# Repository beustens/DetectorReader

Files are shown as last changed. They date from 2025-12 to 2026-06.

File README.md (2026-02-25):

# Detector Reader
Short range, low cost UHF RFID reader based on RF detector

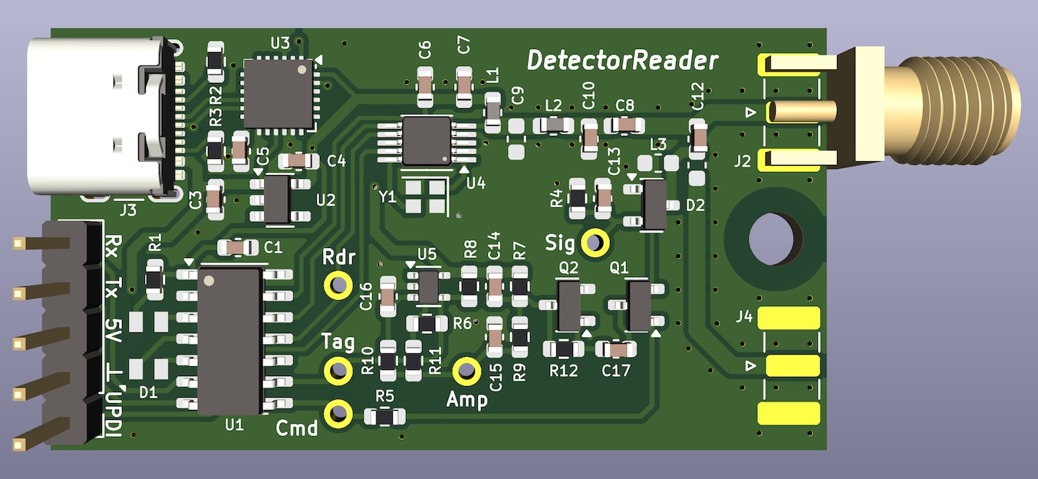
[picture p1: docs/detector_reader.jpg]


## Features
- 0.5m...2m read range depending on antenna and tag (8dBi patch antenna recommended)
- Monostatic or bistatic configuration
- ~15$ of production cost
- Compact size of 46x25mm
- Powersupply via 3...5V or USB
- EPCs are reported via UART or USB (serial) interface (115200 baud)

## Flashing
The firmware is written in AVR-C for the ATtiny814 using the platformIO IDE (extension for Visual STudio Code).

To transfer the firmware to the microcontroller, install [pymcuprog](https://pypi.org/project/pymcuprog/) and build yourself a UPDI programmer from a simple USB-UART converter and a 1kOhm resistor by connecting the resistor between Rx und Tx and connecting Rx to UPDI (Reset pin):
```
                        Vcc                     Vcc
                        +-+                     +-+
                         |                       |
 +---------------------+ |                       | +--------------------+
 | Serial port         +-+                       +-+  AVR device        |
 |                     |     +----------+          |                    |
 |                  TX +-----+   1k     +-----+    |                    |
 |                     |     +----------+     |    |                    |
 |                     |                      |    |                    |
 |                  RX +----------------------+----+ UPDI               |
 |                     |                           |                    |
 |                     +--+                     +--+                    |
 +---------------------+  |                     |  +--------------------+
                         +-+                   +-+
                         GND                   GND
```

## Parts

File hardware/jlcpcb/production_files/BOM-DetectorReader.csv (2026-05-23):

Comment | Designator | Footprint | LCSC | Quantity
MAX41460 | U4 | VSSOP-10_3x3mm_P0.5mm |  | 1
2.7p | C10 | C_0603_1608Metric |  | 1
2.7p | C12 | C_0603_1608Metric |  | 1
BC847C,215 | Q2 | SOT-23 |  | 1
CY7C65211-24LTXI | U3 | QFN-24-1EP_4x4mm_P0.5mm_EP2.6x2.6mm |  | 1
10u | C4 | C_0603_1608Metric |  | 1
IN-P32TATRGB | D1 | LED_SMD_IN-P32TATRGB |  | 1
Combo_Conn | J1 | PinHeader_1x05_P2.54mm_Vertical |  | 1
5.1k | R4 | R_0603_1608Metric |  | 1
220k | R10 | R_0603_1608Metric |  | 1
100n | C1 | C_0603_1608Metric |  | 1
USB_C_Receptacle_USB2.0_16P | J3 | USB_C_Receptacle_GCT_USB4105-xx-A_16P_TopMnt_Horizontal |  | 1
220k | R12 | R_0603_1608Metric |  | 1
5.1k | R3 | R_0603_1608Metric |  | 1
TLV70330DBVR | U2 | SOT-23-5 |  | 1
10k | R5 | R_0603_1608Metric |  | 1
LMV331 | U5 | SOT-353_SC-70-5 |  | 1
1k | R7 | R_0603_1608Metric |  | 1
1u | C5 | C_0603_1608Metric |  | 1
ATtiny814-SS | U1 | SOIC-14_3.9x8.7mm_P1.27mm |  | 1
1k | R9 | R_0603_1608Metric |  | 1
100p | C7 | C_0603_1608Metric |  | 1
CON-SMA-EDGE-S | J2 | SMA_Samtec_SMA-J-P-H-ST-EM1_EdgeMount |  | 1
BC847C,215 | Q1 | SOT-23 |  | 1
1k | R8 | R_0603_1608Metric |  | 1
1M | R6 | R_0603_1608Metric |  | 1
ECS-160-12-37B-CTN-TR | Y1 | Crystal_SMD_2016-4Pin_2.0x1.6mm |  | 1
10k | R11 | R_0603_1608Metric |  | 1
5.1k | R2 | R_0603_1608Metric |  | 1
10n | C6 | C_0603_1608Metric |  | 1
1n | C13 | C_0603_1608Metric |  | 1
1k | R1 | R_0603_1608Metric |  | 1
100p | C8 | C_0603_1608Metric |  | 1
10n | C17 | C_0603_1608Metric |  | 1
5.6n | L1 | L_0603_1608Metric |  | 1
10u | C3 | C_0603_1608Metric |  | 1
1n | C15 | C_0603_1608Metric |  | 1
100p | C16 | C_0603_1608Metric |  | 1
5.6n | L2 | L_0603_1608Metric |  | 1
1n | C14 | C_0603_1608Metric |  | 1
BAT54S | D2 | SOT-23 |  | 1

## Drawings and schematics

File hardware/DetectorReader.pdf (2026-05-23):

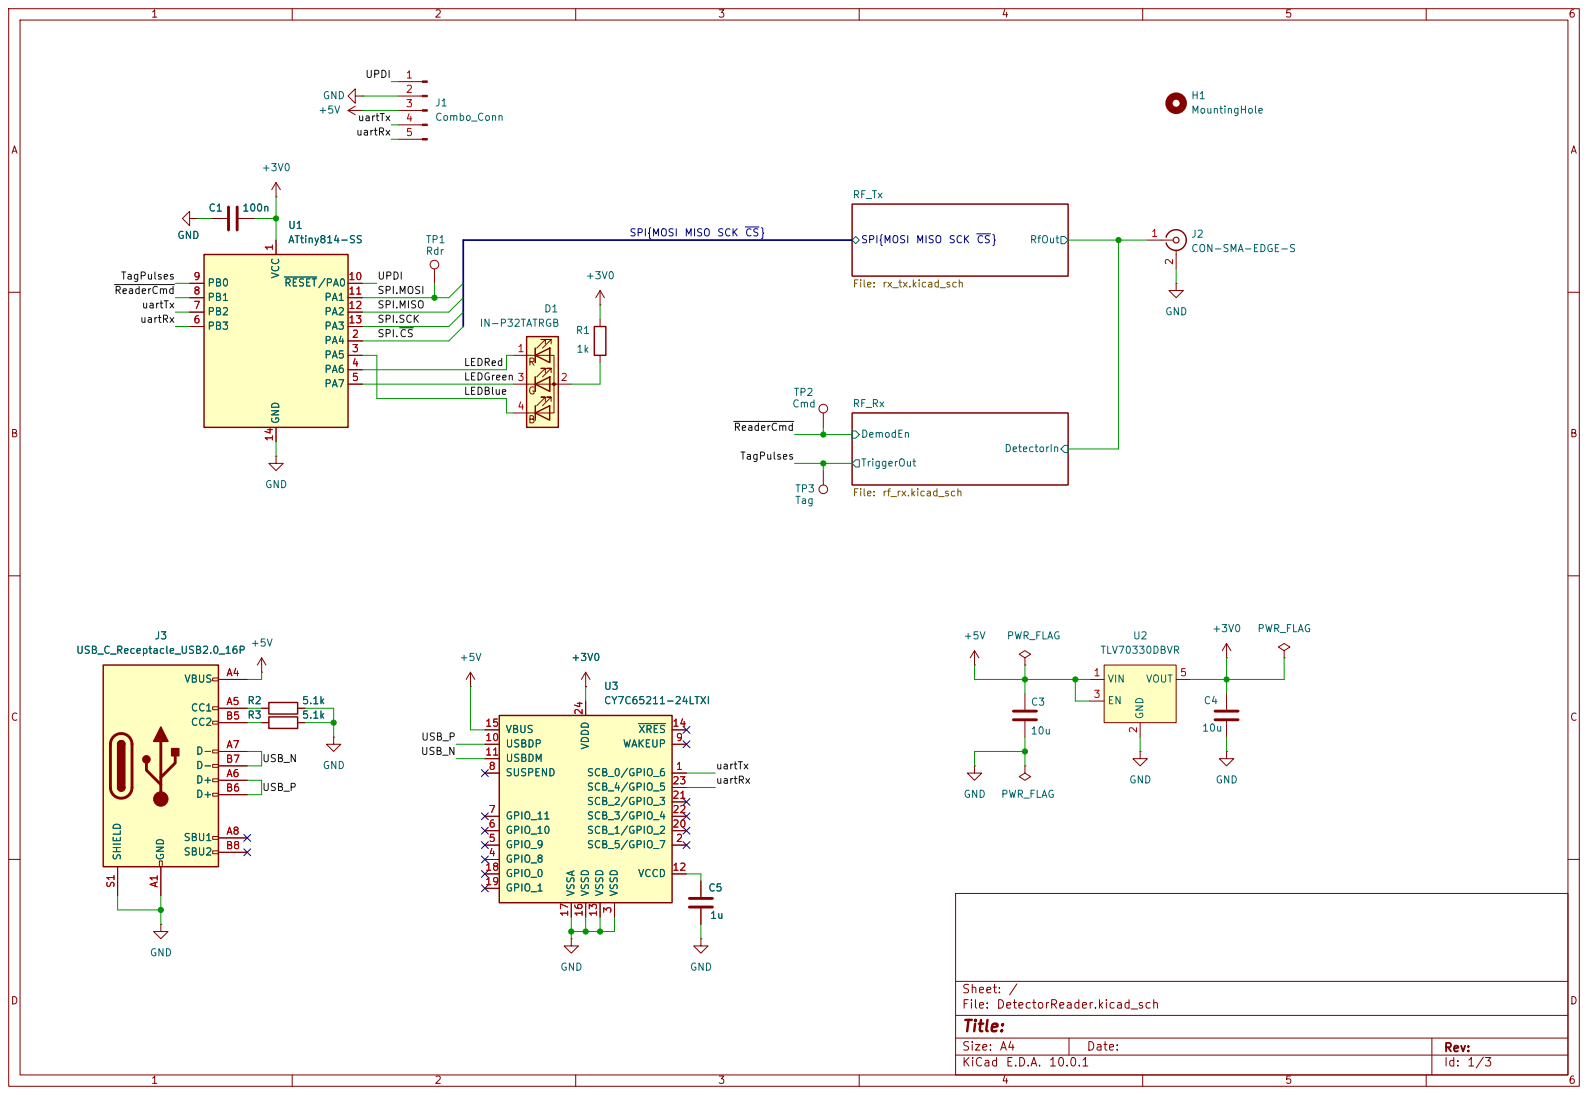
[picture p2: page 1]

uartTx UPDI SPI.MOSI SPI.MISO

Size: A4 | Rev:
KiCad E.D.A. 10.0.1 | Id: 1/3

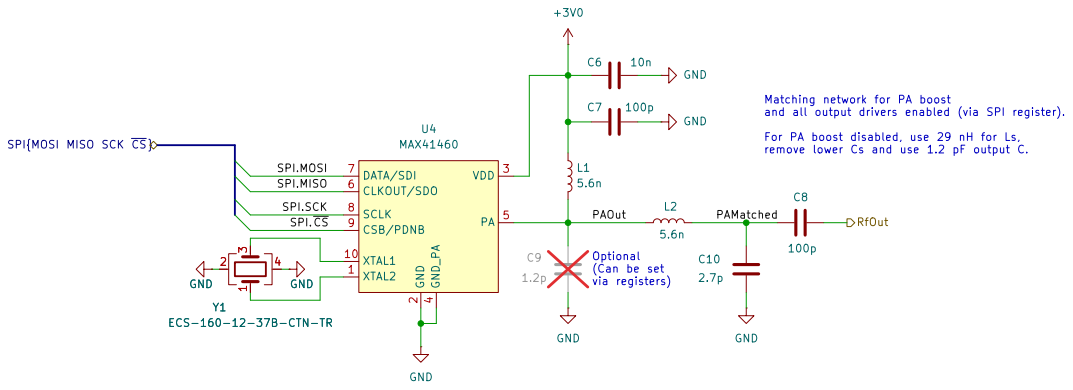
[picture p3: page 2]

Matching network for PA boost and all output drivers enabled (via SPI register). For PA boost disabled, use 29 nH for Ls,

remove lower Cs and use 1.2 pF output C. GND

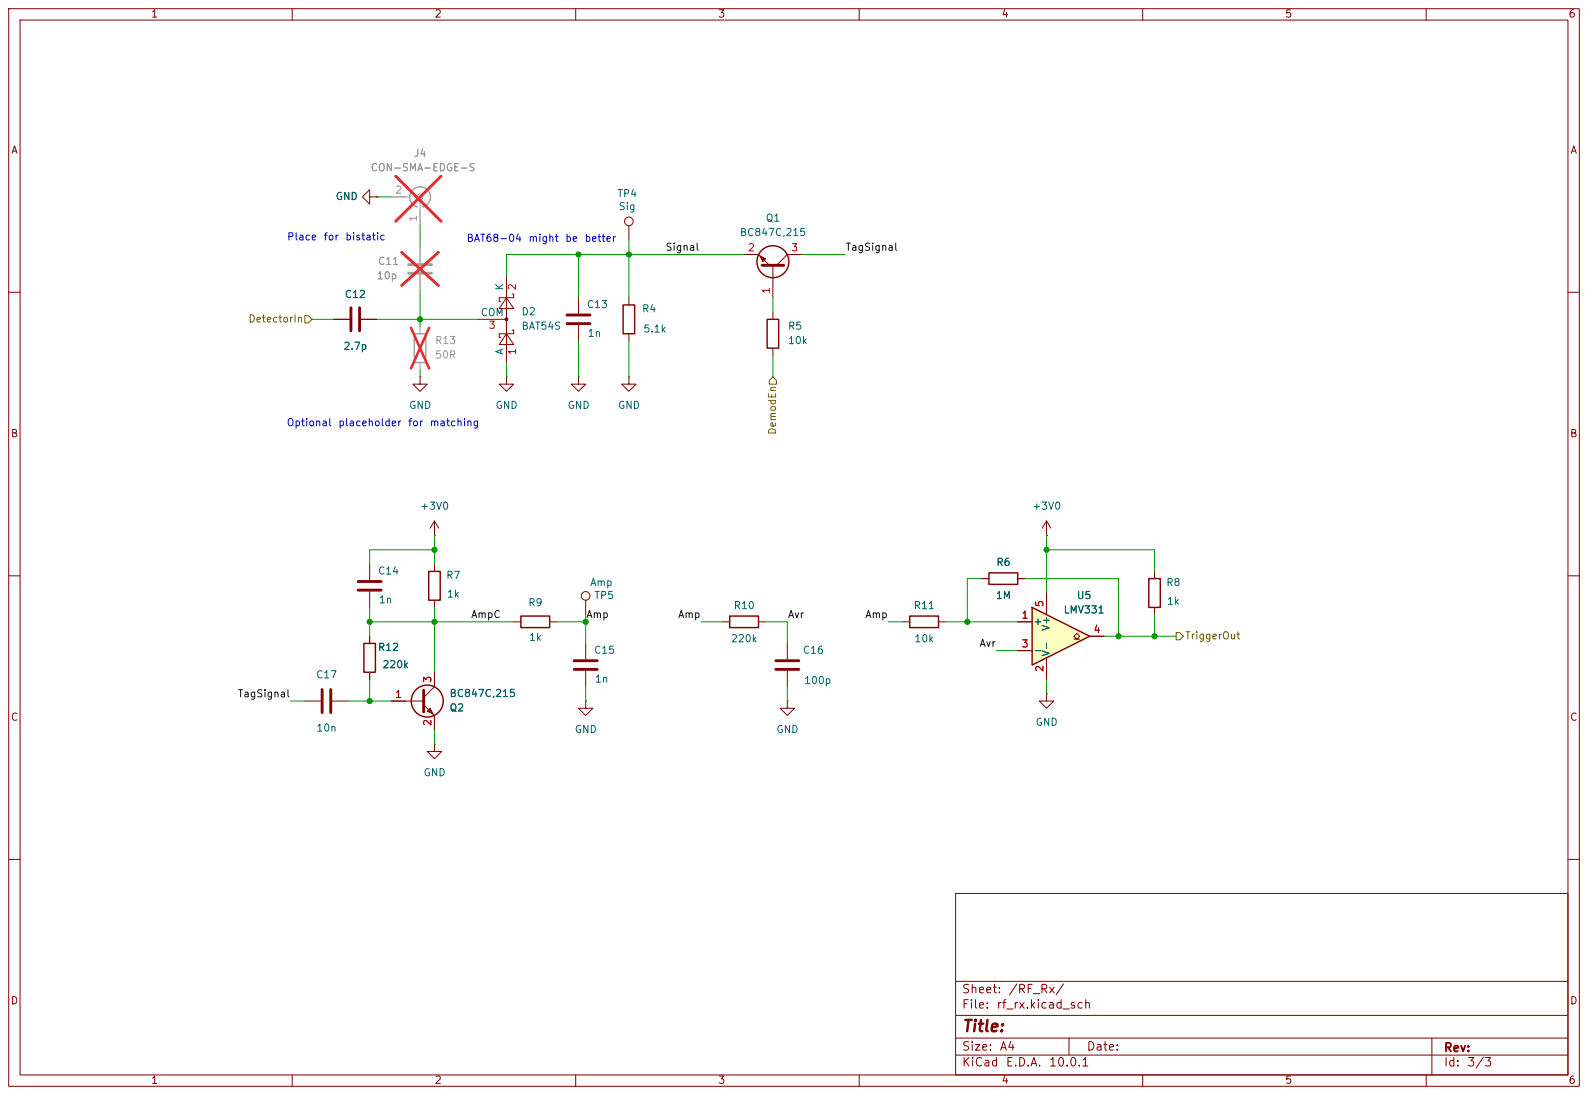
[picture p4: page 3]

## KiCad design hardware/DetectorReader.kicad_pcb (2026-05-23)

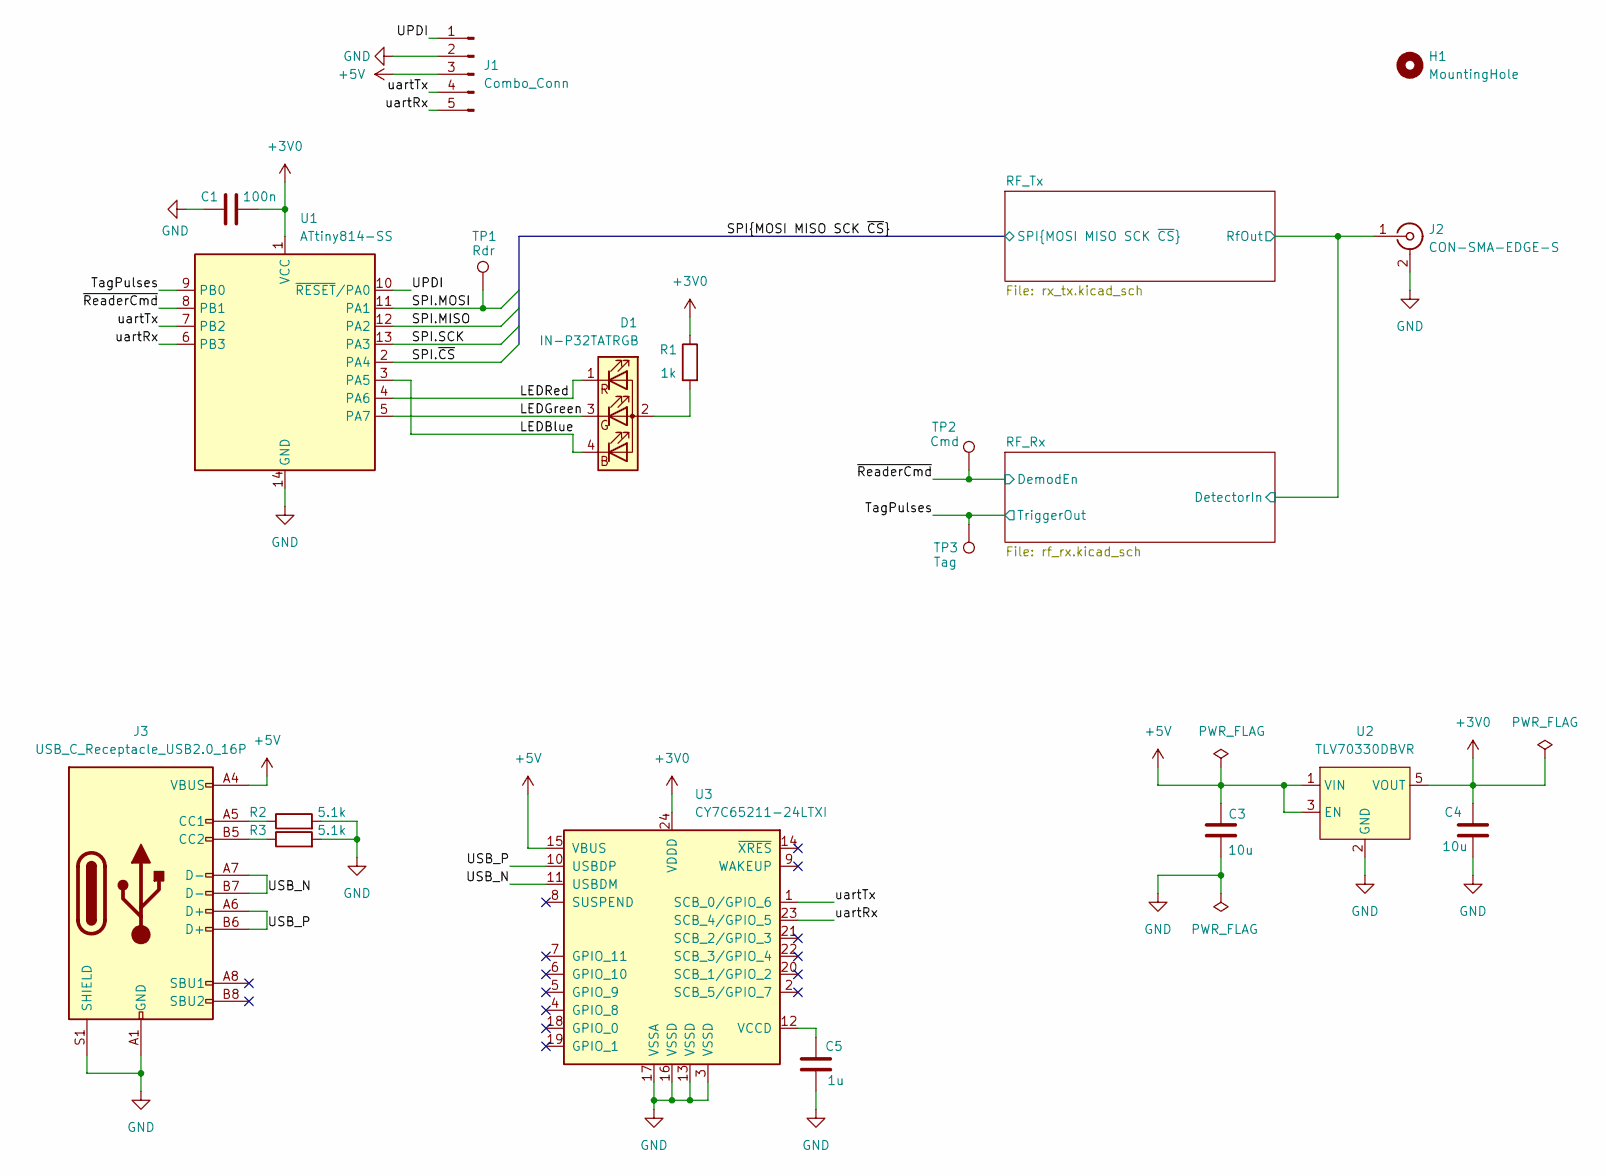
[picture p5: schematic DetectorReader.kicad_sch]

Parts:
C1: 100n; C_0603_1608Metric
C3, C4: 10u; C_0603_1608Metric
C5: 1u; C_0603_1608Metric
D1: IN-P32TATRGB; LED_SMD_IN-P32TATRGB
H1: MountingHole; MountingHole_3.2mm_M3_DIN965
J1: Combo_Conn; PinHeader_1x05_P2.54mm_Vertical
J2: CON-SMA-EDGE-S; SMA_Samtec_SMA-J-P-H-ST-EM1_EdgeMount
J3: USB_C_Receptacle_USB2.0_16P; USB_C_Receptacle_GCT_USB4105-xx-A_16P_TopMnt_Horizontal
R1: 1k; R_0603_1608Metric
R2, R3: 5.1k; R_0603_1608Metric
TP1: Rdr; Single_Pin
TP2: Cmd; Single_Pin
TP3: Tag; Single_Pin
U1: ATtiny814-SS; SOIC-14_3.9x8.7mm_P1.27mm
U2: TLV70330DBVR; SOT-23-5
U3: CY7C65211-24LTXI; QFN-24-1EP_4x4mm_P0.5mm_EP2.6x2.6mm

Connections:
+3V0: C1.2, C4.2, R1.1, U1.1 (VCC), U2.5 (VOUT), U3.24 (VDDD); also elsewhere on the board
+5V: C3.2, J1.3, J3.A4 (VBUS), J3.A9 (VBUS), J3.B4 (VBUS), J3.B9 (VBUS), U2.1 (VIN), U2.3 (EN), U3.15 (VBUS)
/LEDBlue: D1.4 (BK), U1.3 (PA5)
/LEDGreen: D1.3 (GK), U1.5 (PA7)
/LEDRed: D1.1 (RK), U1.4 (PA6)
/RF_Rx/DetectorIn: J2.1 (In); also elsewhere on the board
/SPI.MISO: U1.12 (PA2); also elsewhere on the board
/SPI.MOSI: TP1.1 (1_1), U1.11 (PA1); also elsewhere on the board
/SPI.SCK: U1.13 (PA3); also elsewhere on the board
/SPI.~CS: U1.2 (PA4); also elsewhere on the board
/TagPulses: TP3.1 (1_1), U1.9 (PB0); also elsewhere on the board
/UPDI: J1.1, U1.10 (~RESET/PA0)
/USB_N: J3.A7 (D-), J3.B7 (D-), U3.11 (USBDM)
/USB_P: J3.A6 (D+), J3.B6 (D+), U3.10 (USBDP)
/uartRx: J1.5, U1.6 (PB3), U3.23 (SCB_4/GPIO_5)
/uartTx: J1.4, U1.7 (PB2), U3.1 (SCB_0/GPIO_6)
/~ReaderCmd: TP2.1 (1_1), U1.8 (PB1); also elsewhere on the board
GND: C1.1, C3.1, C4.1, C5.1, J1.2, J2.2 (Ext), J3.A1 (GND), J3.A12 (GND), J3.B1 (GND), J3.B12 (GND), J3.S1 (SHIELD), R2.2, R3.2, U1.14 (GND), U2.2 (GND), U3.3 (VSSD), U3.13 (VSSD), U3.16 (VSSD), U3.17 (VSSA); also elsewhere on the board
unnamed: D1.2 (A), R1.2
unnamed: J3.A5 (CC1), R2.1
unnamed: J3.B5 (CC2), R3.1
unnamed: C5.2, U3.12 (VCCD)

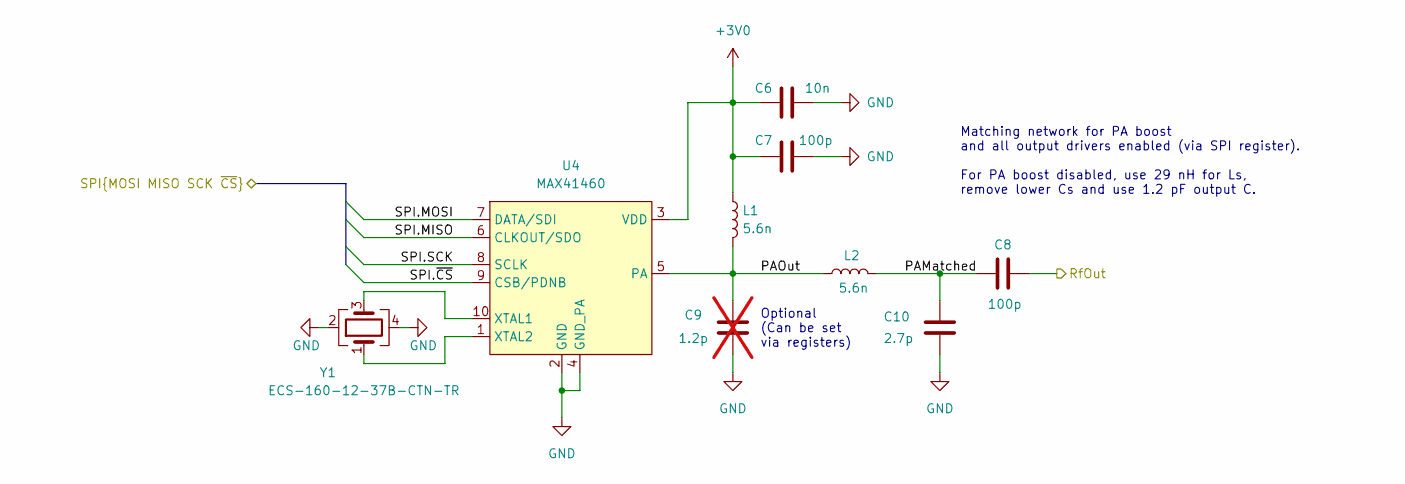
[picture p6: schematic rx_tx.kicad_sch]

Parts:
C6: 10n; C_0603_1608Metric
C7, C8: 100p; C_0603_1608Metric
C9: 1.2p; C_0603_1608Metric; not fitted
C10: 2.7p; C_0603_1608Metric
L1, L2: 5.6n; L_0603_1608Metric
U4: MAX41460; VSSOP-10_3x3mm_P0.5mm
Y1: ECS-160-12-37B-CTN-TR; Crystal_SMD_2016-4Pin_2.0x1.6mm

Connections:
+3V0: C6.1, C7.2, L1.1, U4.3 (VDD); also elsewhere on the board
/RF_Rx/DetectorIn: C8.1; also elsewhere on the board
/RF_Tx/PAMatched: C8.2, C10.1, L2.2
/RF_Tx/PAOut: C9.1, L1.2, L2.1, U4.5 (PA)
/SPI.MISO: U4.6 (CLKOUT/SDO); also elsewhere on the board
/SPI.MOSI: U4.7 (DATA/SDI); also elsewhere on the board
/SPI.SCK: U4.8 (SCLK); also elsewhere on the board
/SPI.~CS: U4.9 (CSB/PDNB); also elsewhere on the board
GND: C6.2, C7.1, C9.2, C10.2, U4.2 (GND), U4.4 (GND_PA), Y1.2, Y1.4; also elsewhere on the board
unnamed: U4.10 (XTAL1), Y1.3
unnamed: U4.1 (XTAL2), Y1.1

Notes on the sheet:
Optional (Can be set via registers)
Matching network for PA boost and all output drivers enabled (via SPI register). For PA boost disabled, use 29 nH for Ls, remove lower Cs and use 1.2 pF output C.

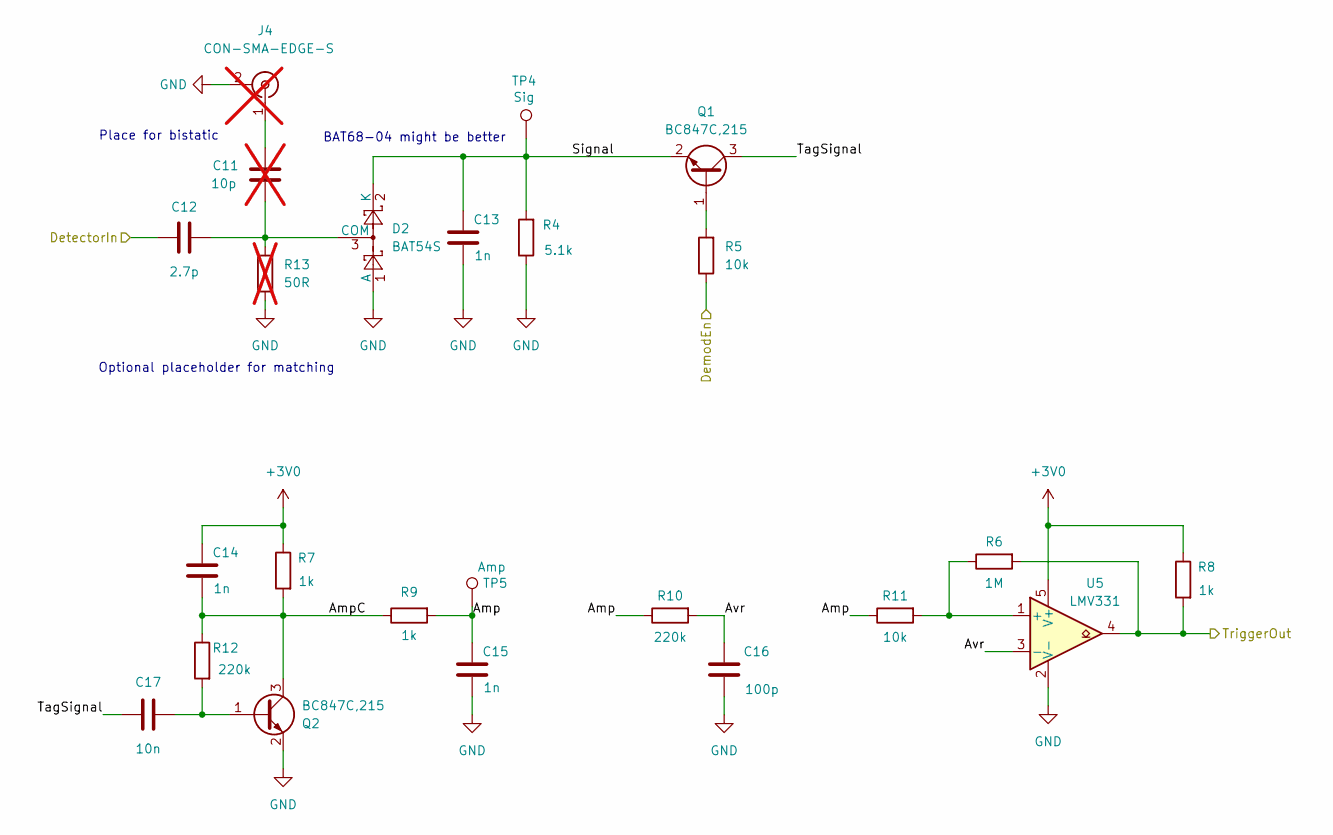
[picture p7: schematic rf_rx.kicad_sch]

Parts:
C11: 10p; C_0603_1608Metric; not fitted
C12: 2.7p; C_0603_1608Metric
C13, C14, C15: 1n; C_0603_1608Metric
C16: 100p; C_0603_1608Metric
C17: 10n; C_0603_1608Metric
D2: BAT54S; SOT-23
J4: CON-SMA-EDGE-S; SMA_Samtec_SMA-J-P-H-ST-EM1_EdgeMount; not fitted
Q1, Q2: BC847C,215; SOT-23
R4: 5.1k; R_0603_1608Metric
R5, R11: 10k; R_0603_1608Metric
R6: 1M; R_0603_1608Metric
R7, R8, R9: 1k; R_0603_1608Metric
R10, R12: 220k; R_0603_1608Metric
R13: 50R; R_0603_1608Metric; not fitted
TP4: Sig; Single_Pin
TP5: Amp; Single_Pin
U5: LMV331; SOT-353_SC-70-5

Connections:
+3V0: C14.1, R7.1, R8.1, U5.5 (V+); also elsewhere on the board
/RF_Rx/Amp: C15.1, R9.2, R10.1, R11.1, TP5.1 (1_1)
/RF_Rx/AmpC: C14.2, Q2.3 (C), R7.2, R9.1, R12.1
/RF_Rx/Avr: C16.1, R10.2, U5.3 (-)
/RF_Rx/DetectorIn: C12.2; also elsewhere on the board
/RF_Rx/Signal: C13.1, D2.2 (K), Q1.2 (E), R4.2, TP4.1 (1_1)
/RF_Rx/TagSignal: C17.1, Q1.3 (C)
/TagPulses: R6.2, R8.2, U5.4; also elsewhere on the board
/~ReaderCmd: R5.1; also elsewhere on the board
GND: C13.2, C15.2, C16.2, D2.1 (A), J4.2 (Ext), Q2.2 (E), R4.1, R13.2, U5.2 (V-); also elsewhere on the board
unnamed: C11.2, C12.1, D2.3 (COM), R13.1
unnamed: C11.1, J4.1 (In)
unnamed: Q1.1 (B), R5.2
unnamed: C17.2, Q2.1 (B), R12.2
unnamed: R6.1, R11.2, U5.1 (+)

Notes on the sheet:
Optional placeholder for matching
Place for bistatic
BAT68-04 might be better

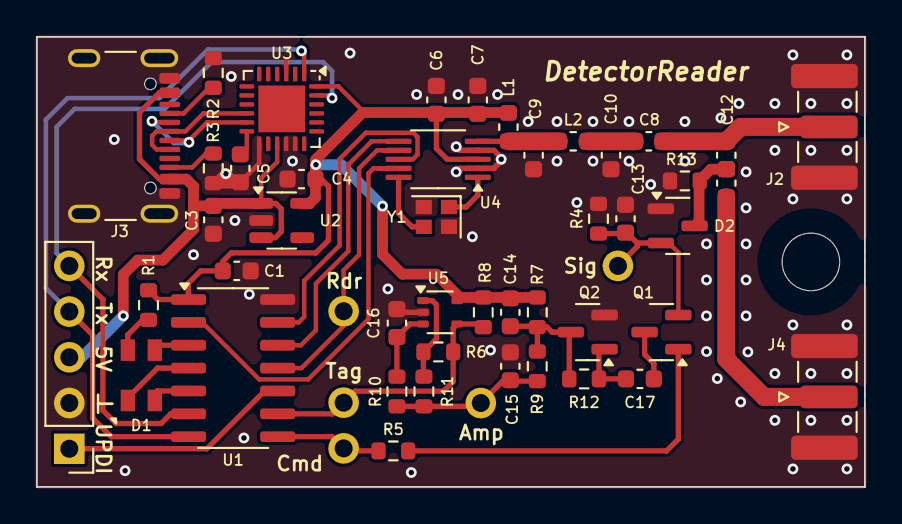
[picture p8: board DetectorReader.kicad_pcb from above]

Board: 2 copper layers, 46.0 x 25.0 mm, 51 parts (0 on the bottom side), 36 nets.

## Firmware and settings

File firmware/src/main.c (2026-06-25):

#include <stdint.h> // for uint8_t, uint16_t, etc.
#include <util/delay.h> // for waiting
#include <stdio.h> // for sprintf
#include <string.h>	// for string operations like cmp and cat
#include <avr/interrupt.h>	// for sei(), cli() and ISR()
#include "gpio.h"
#include "main.h"
#include "rfid.h"
#include "max41460.h"


ISR(USART0_RXC_vect) {
	char nextChar = USART0.RXDATAL; // new char available

	// track received string
	static uint8_t charCnt = 0;
	if (nextChar != STR_TERM && charCnt < UART_MAX_LEN) {
		// still getting valid chars
		readStr[charCnt++] = nextChar;
	} else {
		// end of string
		readStr[charCnt] = '\0';
		charCnt = 0;
		gotUARTCmd = TRUE;
	}
}

int main() {
	// setup
	configClock();
	configGPIO();
	configSPI();
	configTCA();
	configTCB();
	configRTC();
	configUSART();
	sei(); // enable interrupts

	LED_PORT.OUTCLR = LED_RED_PIN; // enable red LED
	startTransmitter();
	enablePower(TRUE);
	LED_PORT.OUTSET = LED_RED_PIN; // disable LED

	uint8_t slot = 0;

	// main program loop
	while (TRUE) {
		// parse incoming UART command
		if (gotUARTCmd) {
			parseCommand((char*)readStr);
			gotUARTCmd = FALSE;
		}
		
		// transmit Query periodicly
		if (RTC.INTFLAGS & RTC_CMP_bm) {
			// RTC interrupt bit set
			RTC.INTFLAGS |= RTC_CMP_bm; // clear interrupt bit
			RTC.CNT = 0; // restart RTC
			if (slot == 0) {
				runSequence(queryPulses);
			} else if (slot > POPULATION) {
				slot = 0;
			} else {
				slot++;
				runSequence(queryRepPulses);
			}
		}

		// receive tag responses
		trackTagPulses();
		if (gotEPC) {
			LED_PORT.OUTCLR = LED_GREEN_PIN; // tag EPC detected indicator
			sendEPC();
			gotEPC = FALSE;
		}
	}

	return 0;
}

void sendEPC() {
	// format and send EPC via UART
	static char hexStr[3];
	for (iEPCByte = NUM_EPC_PREFIX; iEPCByte < NUM_EPC_PREFIX+NUM_EPC_BYTES; iEPCByte++) {
		// format EPC bytes as hex ascii strings
		sprintf(hexStr, "%.2x", epc[iEPCByte]);
		sendStringRaw(hexStr);
	}
	sendChar(STR_TERM);
}

void parseCommand(const char* pStr) {
	// parse command
	if (strncmp(pStr, "POW", 3) == 0) {
		// enable/disable power
		pStr += 3;
		if (*pStr == '?') {
			// host wants to know if power (carrier, unmodulated) is enabled
			sendString((powerEnable) ? "ON" : "OFF");
		} else {
			// host wants to set power output
			pStr += 2; // skip " O"
			enablePower((*pStr == 'N'));
			sendString("1"); // confirm
		}
	} else {
		// no valid command
		sendString("Invalid command");
	}
}

void configClock() {
	// configure CPU frequency to 20MHz
	CCP = CCP_IOREG_gc; // disable protection to configure clock frequency
	CLKCTRL.MCLKCTRLA = CLKCTRL_CLKSEL_OSC20M_gc; // use 20 MHz internal clock as source
	CCP = CCP_IOREG_gc; // disable protection to configure clock frequency
	CLKCTRL.MCLKCTRLB = 0; // no prescale divider
}

void configUSART() {
	USART0.BAUD = (uint16_t)USART0_BAUD_RATE(115200); // set baudrate
	USART0.CTRLB |= USART_RXEN_bm | USART_TXEN_bm; // enable RX | TX
	USART0.CTRLA |= USART_RXCIF_bm; // enable interrupt on receive complete
	//PORTMUX_CTRLB |= PORTMUX_USART0_bm; // enable alternative UART pins
	//PORTA.DIRSET = PIN1_bm; // PA1 is the alternative TxD pin
	PORTB.DIRSET = PIN2_bm; // PB2 is the default TxD pin
}

void sendChar(const char c) {
	while (!(USART0.STATUS & USART_DREIF_bm)); // wait until the transmit DATA register is empty
	USART0.TXDATAL = c; // put char into buffer
}

void sendString(const char* pStr) {
	// for all characters in string until STR_TERM
	while(*pStr && (*pStr != STR_TERM)) {
		sendChar(*pStr++);
	}
	// append string termination
	sendChar(STR_TERM);
}

void sendStringRaw(const char* pStr) {
	// for all characters in string
	while(*pStr) {
		sendChar(*pStr++);
	}
}

void configRTC() {
	// config realtime clock
	RTC.CLKSEL = RTC_CLKSEL_INT32K_gc; // use internal 32.768kHz clock
	RTC.CMP = 200; // compare to this value
	RTC.INTCTRL = RTC_CMP_bm; // enable interrupt on compare
	RTC.CTRLA = RTC_RTCEN_bm; // enable RTC
}

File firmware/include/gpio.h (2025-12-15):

#include <avr/io.h> // for microcontroller specific peripheral definitions

// LEDs (low active)
#define LED_PORT            PORTA
#define LED_RED_PIN         PIN6_bm
#define LED_GREEN_PIN       PIN7_bm
#define LED_BLUE_PIN        PIN5_bm

// reader command
#define READER_PORT         PORTA
#define SPI_MOSI            PIN1_bm
#define SPI_MISO            PIN2_bm
#define SPI_SCK             PIN3_bm
#define SPI_CS              PIN4_bm
#define READER_PULSE_PIN    SPI_MOSI

#define READER_CMD_PORT     PORTB
#define READER_CMD_PIN      PIN1_bm

// tag response
// see rfid.c -> configTCB()

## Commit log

2022-08-01 splitted quad opamp into dual opamp and comparator for better digitalization and smaller board
    [BOM-DetectorReader.csv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]
2022-08-18 fixed unreliable reader query transmit
    [main.c]
2022-08-19 Simulation with rail-to-rail opamp
2022-08-23 increased tolerance to substantially increase read range
    [main.c]
2022-08-23 changed resistor values in simulation to reduce diversity
2022-08-23 optimized resistor value according to real world test
2022-08-24 Updated schematic, PCB and fabrication files
    [BOM-DetectorReader.csv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]
2022-09-07 changed R10 to 12k to increase tag pulse detection trigger threshold
    [BOM-DetectorReader.csv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]
2025-12-15 Rev 2. Using USB-C, configurable Tx, op-amp based LF amplifier, tri-color indicator. Using platformIO for firmware, splitted code into separate files.
    [BOM-DetectorReader.csv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]
2025-12-16 updated production files
    [DetectorReader-CuBottom.gbr, DetectorReader-CuTop.gbr, DetectorReader-EdgeCuts.gbr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]
2026-01-09 fixed frequency pll calculation
    [max41460.c]
2026-02-18 Rev 3. Back to transistor-based design since op-amp approach did not work well. Using UART bridge from other brand as FTDI was sold out.
    [BOM-DetectorReader.csv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]
2026-02-19 Rev 4. Removed coupler and detector IC. Using simple diode as detector.
    [BOM-DetectorReader.csv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]
2026-02-24 Fixed UART bridge power supply. Made board 1 mm shorter.
    [BOM-DetectorReader.csv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]
2026-02-25 C12 is now 2.7pF to solve issue with too high detector voltage and reduce BOM
    [DetectorReader.csv, rf_rx.kicad_sch]
2026-05-23 Fixed connector pinout according to silkscreen
    [BOM-DetectorReader.csv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]
